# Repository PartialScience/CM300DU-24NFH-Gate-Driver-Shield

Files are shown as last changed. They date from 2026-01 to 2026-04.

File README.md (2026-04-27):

# CM300DU-24NFH IGBT Gate Driver / Protection Shield

KiCad files for a small daughter-board that mounts directly over a Mitsubishi
**CM300DU-24NFH** dual IGBT module to provide gate drive coupling and
collector–emitter transient protection. Designed for use in my first
[DRSSTC](https://en.wikipedia.org/wiki/Tesla_coil#Solid-state_Tesla_coil)
build.

## What the board does

The shield carries four electrically isolated circuits on a single PCB:

- **Two gate-drive networks** — one per IGBT in the module. Each takes the
  output of a gate-drive transformer and feeds the gate through an
  anti-parallel resistor / Schottky diode pair. The asymmetric turn-on vs.
  turn-off impedance adds a small amount of switching hysteresis, which
  prevents both IGBTs in a half-bridge from being briefly in conduction at the
  same time and shorting the DC bus.
- **Two collector–emitter clamp networks** — one per IGBT. Each is a string of
  series TVS diodes across the C–E terminals to catch fast switching
  transients that the main bus snubber may not absorb quickly enough,
  protecting the IGBT from voltage spikes during turn-off.

Mounting the protection on its own PCB directly above the module keeps the
loop area between the clamps and the IGBT terminals as small as possible,
which is what makes the clamps actually effective at high di/dt.

## Key components

| Function | Part |
| --- | --- |
| IGBT module (footprint) | Mitsubishi CM300DU-24NFH |
| Primary TVS (C–E clamp string) | Vishay 1.5KE220CA (×8) |
| Secondary TVS | P6KE30CA (×2) |
| Gate-drive Schottky | 1N5819 (×2) |
| Gate trim pot | Bourns 3362X-1-100LF (×2) |
| Gate-drive headers | Molex 22-01-2021 (×2) |
| Output headers | Molex 171857-0002 (×2) |

See [`bom.csv`](bom.csv) for the full bill of materials.

## Repository contents

- `Gate_Driver.kicad_*` — KiCad 7+ project (schematic, PCB, design rules)
- `PowerIGBTs.kicad_sym` — symbol library for the IGBT module
- `Library.pretty/` — footprint library
- `CM300DU-24NFH Outline*.dxf` — mechanical outline of the IGBT module
- `Gate_Driver*.step` — 3D models of various board revisions
- `Custom-Connector.stp` — 3D model of the gate-drive connector
- `BoardTop.png`, `Logo.png` — render and silkscreen artwork
- `bom.csv` — bill of materials

## License

Released under the MIT License — see [`LICENSE`](LICENSE).

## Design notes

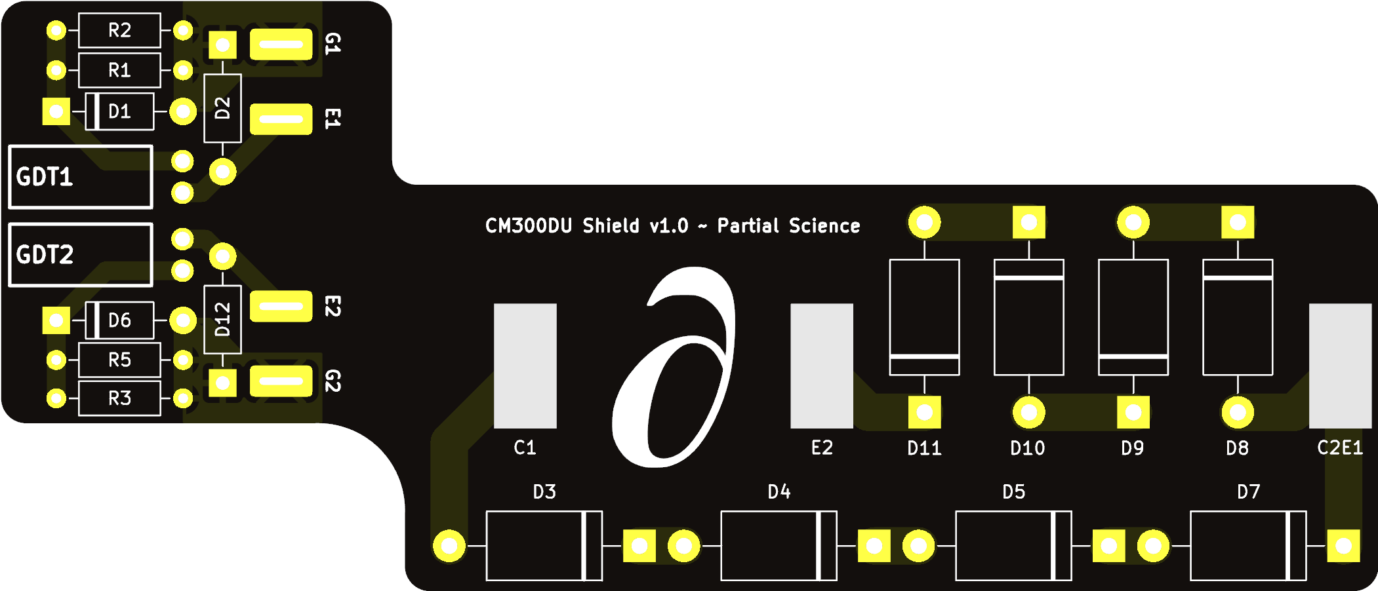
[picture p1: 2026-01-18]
BoardTop.png

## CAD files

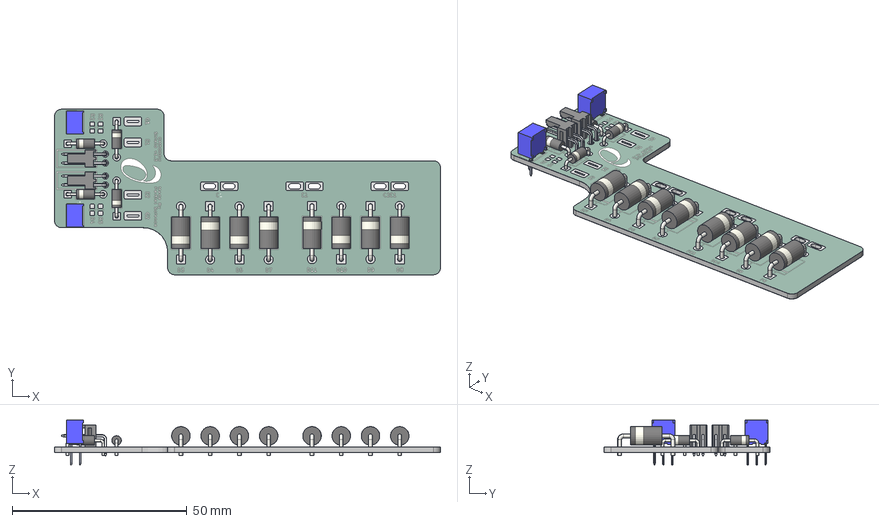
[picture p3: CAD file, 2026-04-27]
Gate_Driver_v1.3.step
110.3 x 47.3 x 12.8 mm
D_DO-201AE_P15.24mm_Horizontal x 8
3362X-1-100LF x 2
D_DO-41_SOD81_P10.16mm_Horizontal x 4
Gate_Driver_copper
Gate_Driver_pad
Gate_Driver_silkscreen
Gate_Driver_soldermask
Gate_Driver_PCB

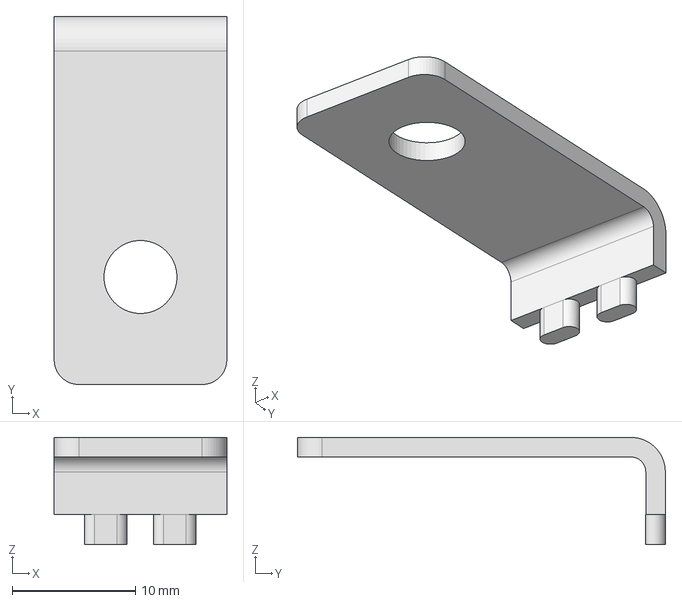
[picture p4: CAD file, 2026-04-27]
Custom-Connector.stp
14.0 x 29.8 x 8.69 mm

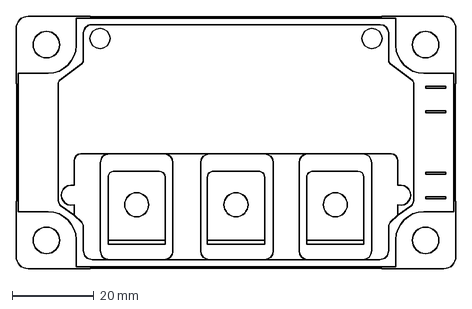
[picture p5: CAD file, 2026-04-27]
CM300DU-24NFH Outline 2.dxf
107.9 x 61.9 mm

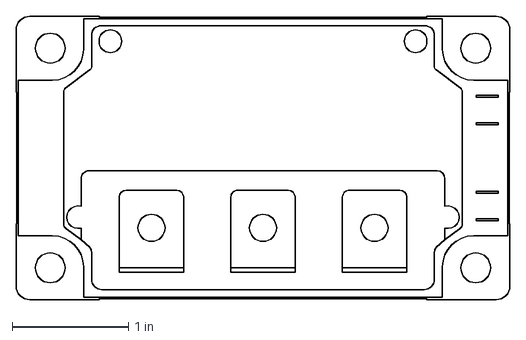
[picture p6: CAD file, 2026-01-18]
CM300DU-24NFH Outline.dxf
4.25 x 2.44 in

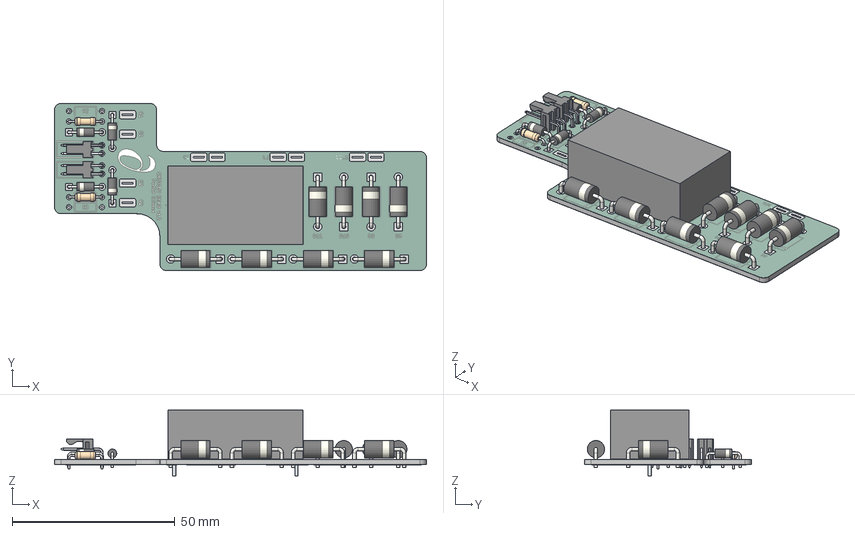
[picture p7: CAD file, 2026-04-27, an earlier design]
Gate_Driver_v1.2.step
114.1 x 51.3 x 20.1 mm
D_DO-201AE_P15.24mm_Horizontal x 8
D_DO-41_SOD81_P10.16mm_Horizontal x 4
R_Axial_DIN0207_L6.3mm_D2.5mm_P10.16mm_Horizontal x 2
Leads
Gate_Driver_copper
Gate_Driver_pad
Gate_Driver_silkscreen
Gate_Driver_soldermask
Gate_Driver_PCB

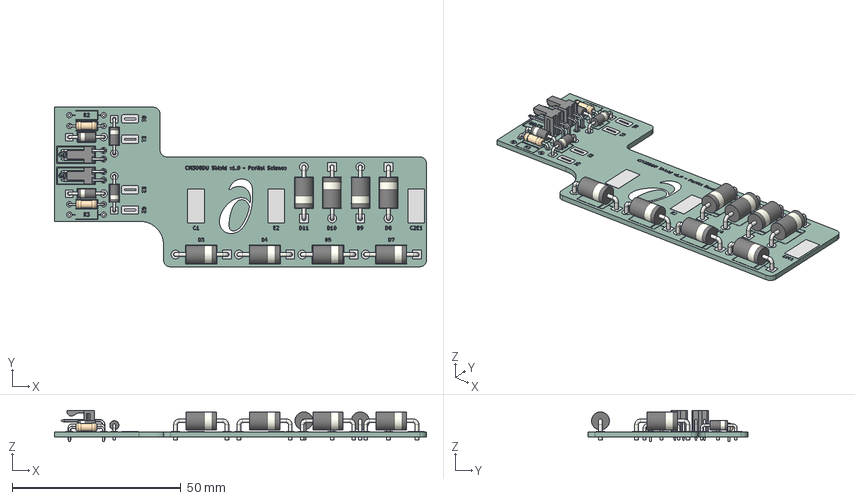
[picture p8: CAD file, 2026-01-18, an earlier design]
Gate_Driver.step
110.3 x 47.3 x 9.27 mm
D_DO-201AE_P15.24mm_Horizontal x 8
D_DO-41_SOD81_P10.16mm_Horizontal x 4
R_Axial_DIN0207_L6.3mm_D2.5mm_P10.16mm_Horizontal x 2
Gate_Driver_pad
Gate_Driver_silkscreen
Gate_Driver_PCB

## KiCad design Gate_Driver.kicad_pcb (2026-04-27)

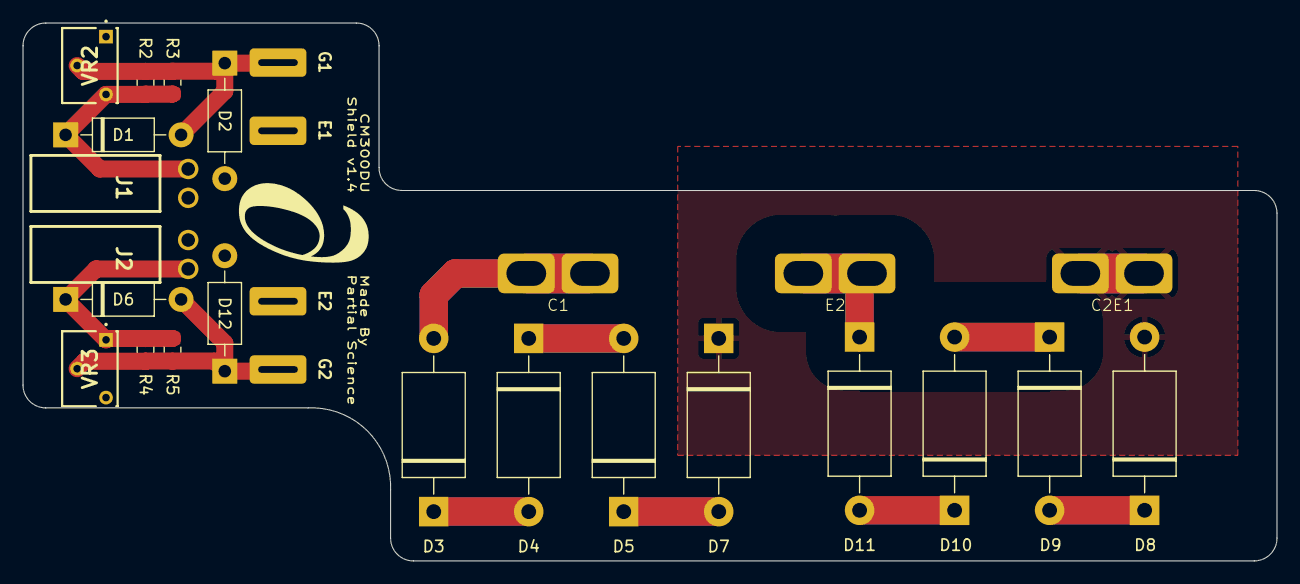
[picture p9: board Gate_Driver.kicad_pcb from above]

Board: 2 copper layers, 110.3 x 47.3 mm, 24 parts (0 on the bottom side), 15 nets.

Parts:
C1: C1; Custom CM300DU Terminal Connector
C2E1: C2E1; Custom CM300DU Terminal Connector
D1, D6: 1N5819; D_DO-41_SOD81_P10.16mm_Horizontal
D2, D12: P6KE30CA; D_DO-41_SOD81_P10.16mm_Horizontal
D3, D4, D5, D7, D8, D9, D10, D11: 1.5KE220CA; D_DO-201AE_P15.24mm_Horizontal
E2: E2; Custom CM300DU Terminal Connector
J1, J2: 171857-0002
Q1: CM300DU-24NFH
R2, R3, R4, R5: R; R_0805_2012Metric_Pad1.20x1.40mm_HandSolder
VR2, VR3: 3362X-1-100LF; 3362X1100LF

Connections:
unnamed: C1.1, D3.2 (A2)
unnamed: C2E1.1, D7.1 (A1), D8.2 (A2)
unnamed: D1.2 (A), D2.1 (K), Q1.1 (G1), R2.2, R3.2, VR2.2
unnamed: D1.1 (K), J1.2, R2.1, R3.1, VR2.3
unnamed: D2.2 (A), J1.1, Q1.2 (E1)
unnamed: D3.1 (A1), D4.2 (A2)
unnamed: D4.1 (A1), D5.2 (A2)
unnamed: D5.1 (A1), D7.2 (A2)
unnamed: D6.1 (K), J2.1, R4.1, R5.1, VR3.1
unnamed: D8.1 (A1), D9.2 (A2)
unnamed: D10.1 (A1), D11.2 (A2)
unnamed: D9.1 (A1), D10.2 (A2)
unnamed: D11.1 (A1), E2.1
unnamed: D12.2 (A), J2.2, Q1.3 (E2)
unnamed: D6.2 (A), D12.1 (K), R4.2, R5.2, VR3.2

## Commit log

2026-01-05 inital commit
    [CM300DU-24NFH Outline.dxf, Gate_Driver.kicad_pcb, Gate_Driver.kicad_sch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]
2026-01-18 Implment up to V1.1
    [bom.csv]
2026-01-18 Remove all ignored files from the repository
    [bom.csv]
2026-01-19 Design done with smaller cap
    [CM300DU-24NFH Outline 2.dxf, Gate_Driver.kicad_pcb, Gate_Driver.kicad_sch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]
2026-01-19 minor tweaks
    [Gate_Driver.kicad_pcb, Gate_Driver.kicad_sch]
2026-01-20 Added pots and re-routed
    [Gate_Driver.kicad_pcb, Gate_Driver.kicad_sch]
2026-01-20 Polish design and finish routing
    [Gate_Driver.kicad_pcb, Gate_Driver_old.kicad_pcb]
2026-01-27 Clean up bom and minor PCB changes
    [Custom-Connector.stp, Gate_Driver.kicad_pcb, Gate_Driver.kicad_sch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]
2026-01-27 Route longer C1-E1 trace as a filled zone
    [Gate_Driver.kicad_pcb, Gate_Driver.kicad_sch]
2026-04-27 Rewrite README with full project description
    Replace the 2-line stub with a description of the CM300DU-24NFH gate-driver
    shield: the four isolated circuits (two gate-drive transformer networks
    with hysteresis-shaping diode/resistor pairs, two collector-emitter TVS
    strings), a key-parts table, and a guide to the repo layout.
2026-04-27 Refresh PCB UUIDs, bump mask-to-copper clearance, regenerate iBOM
    - Gate_Driver.kicad_pro: solder_mask_to_copper_clearance 0 -> 0.005,
    add ngspice block written by KiCad on first simulation open
    - Gate_Driver.kicad_pcb: footprint UUID churn from a re-save
    - bom/ibom.html: regenerated interactive BOM
    [Gate_Driver.kicad_pcb]
